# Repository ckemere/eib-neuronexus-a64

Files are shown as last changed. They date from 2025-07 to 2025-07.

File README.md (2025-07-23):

# EIB for Neuronexus A64 probes

- 64 electrodes
- Power ground (GND) and amplifier reference (REF) exposed via 2.54mm header
- Compatible with
  [headstage-64](https://github.com/open-ephys/onix-headstage-64) Rev. 1.3 and 1.3B, [headstage-64s](https://github.com/open-ephys/onix-headstage-64s), and the [low-profile headstage](https://open-ephys.org/acquisition-system/low-profile-spi-headstage-64ch). 

# Notes about this fork:
This repository is a fork of https://github.com/open-ephys/eib-neuronexus-a64. 
I've replaced the through-hole connector from
that design with a SMD connector (i.e., FOLC-110-02-S-Q-P). While this makes
alignment of the two connectors much more challenging, it allows for
fabrication with a standard 2-layer PCB process with 6 mil trace/space.

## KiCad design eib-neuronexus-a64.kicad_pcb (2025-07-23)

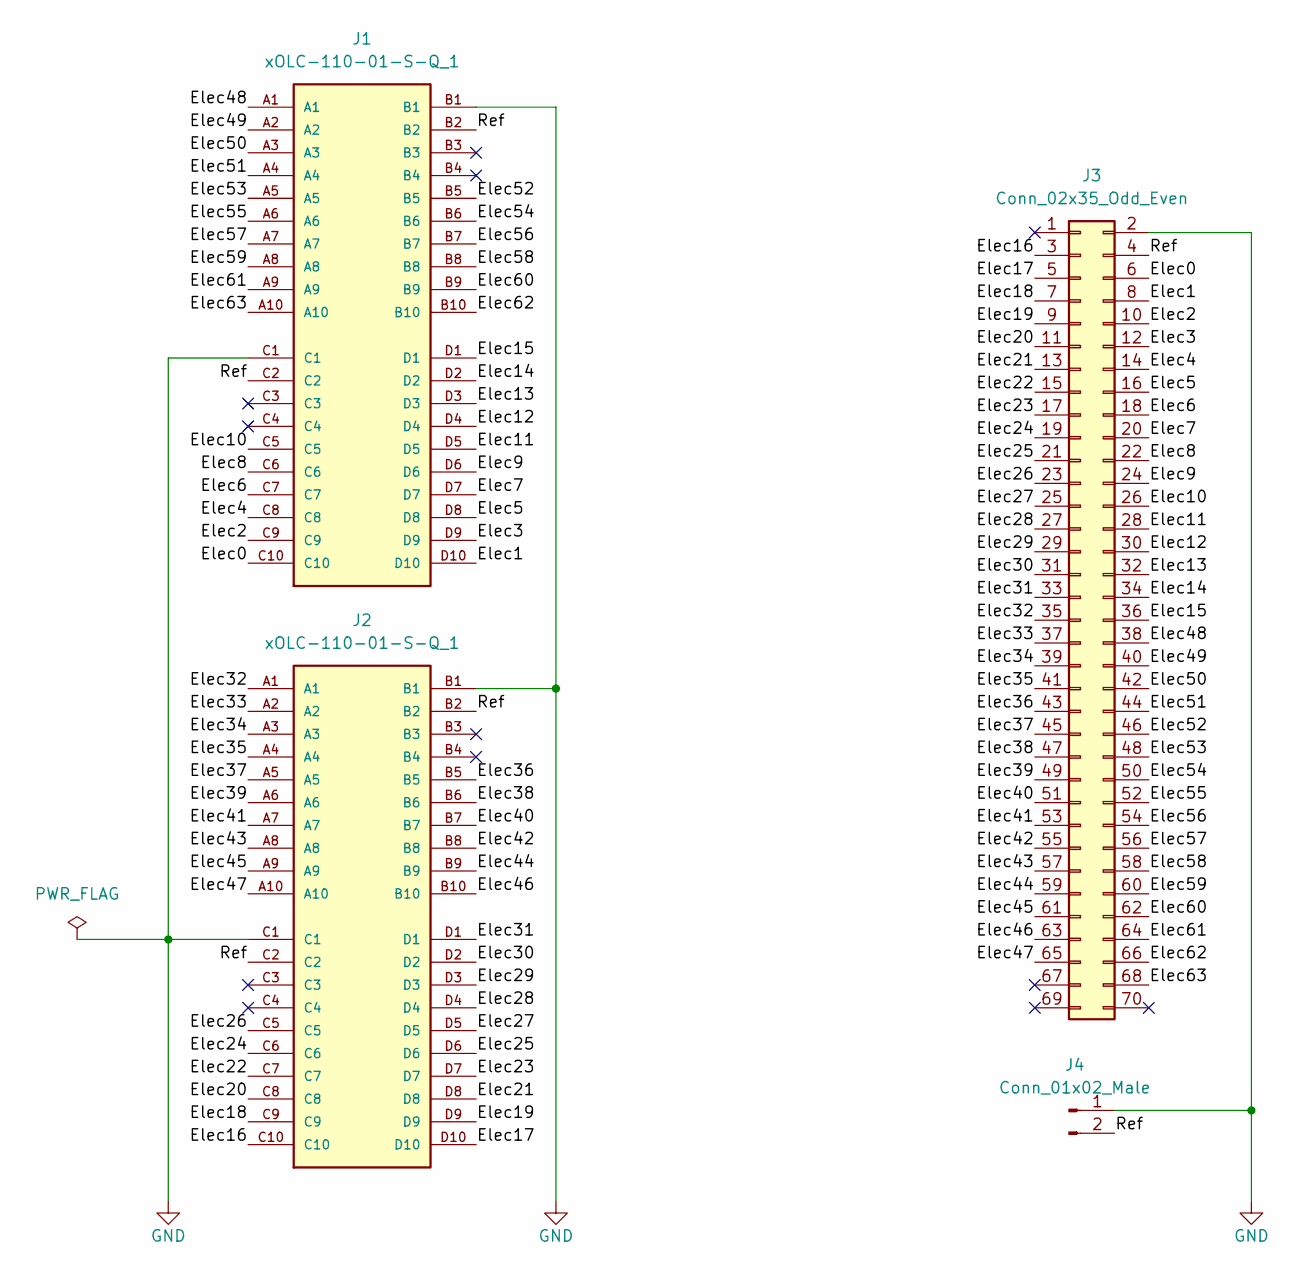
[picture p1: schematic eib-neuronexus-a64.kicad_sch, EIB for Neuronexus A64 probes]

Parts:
J1, J2: xOLC-110-01-S-Q_1; SAMTEC_FOLC-110-02-S-Q-LC
J3: Conn_02x35_Odd_Even; HIROSE_DF40C(2.0)-70DS-0.4V(51)
J4: Conn_01x02_Male; PinHeader_1x02_P2.54mm_Horizontal

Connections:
/Elec0: J1.C10, J3.6
/Elec1: J1.D10, J3.8
/Elec2: J1.C9, J3.10
/Elec3: J1.D9, J3.12
/Elec4: J1.C8, J3.14
/Elec5: J1.D8, J3.16
/Elec6: J1.C7, J3.18
/Elec7: J1.D7, J3.20
/Elec8: J1.C6, J3.22
/Elec9: J1.D6, J3.24
/Elec10: J1.C5, J3.26
/Elec11: J1.D5, J3.28
/Elec12: J1.D4, J3.30
/Elec13: J1.D3, J3.32
/Elec14: J1.D2, J3.34
/Elec15: J1.D1, J3.36
/Elec16: J2.C10, J3.3
/Elec17: J2.D10, J3.5
/Elec18: J2.C9, J3.7
/Elec19: J2.D9, J3.9
/Elec20: J2.C8, J3.11
/Elec21: J2.D8, J3.13
/Elec22: J2.C7, J3.15
/Elec23: J2.D7, J3.17
/Elec24: J2.C6, J3.19
/Elec25: J2.D6, J3.21
/Elec26: J2.C5, J3.23
/Elec27: J2.D5, J3.25
/Elec28: J2.D4, J3.27
/Elec29: J2.D3, J3.29
/Elec30: J2.D2, J3.31
/Elec31: J2.D1, J3.33
/Elec32: J2.A1, J3.35
/Elec33: J2.A2, J3.37
/Elec34: J2.A3, J3.39
/Elec35: J2.A4, J3.41
/Elec36: J2.B5, J3.43
/Elec37: J2.A5, J3.45
/Elec38: J2.B6, J3.47
/Elec39: J2.A6, J3.49
/Elec40: J2.B7, J3.51
/Elec41: J2.A7, J3.53
/Elec42: J2.B8, J3.55
/Elec43: J2.A8, J3.57
/Elec44: J2.B9, J3.59
/Elec45: J2.A9, J3.61
/Elec46: J2.B10, J3.63
/Elec47: J2.A10, J3.65
/Elec48: J1.A1, J3.38
/Elec49: J1.A2, J3.40
/Elec50: J1.A3, J3.42
/Elec51: J1.A4, J3.44
/Elec52: J1.B5, J3.46
/Elec53: J1.A5, J3.48
/Elec54: J1.B6, J3.50
/Elec55: J1.A6, J3.52
/Elec56: J1.B7, J3.54
/Elec57: J1.A7, J3.56
/Elec58: J1.B8, J3.58
/Elec59: J1.A8, J3.60
/Elec60: J1.B9, J3.62
/Elec61: J1.A9, J3.64
/Elec62: J1.B10, J3.66
/Elec63: J1.A10, J3.68
/Ref: J1.B2, J1.C2, J2.B2, J2.C2, J3.4, J4.2
GND: J1.B1, J1.C1, J2.B1, J2.C1, J3.2, J4.1

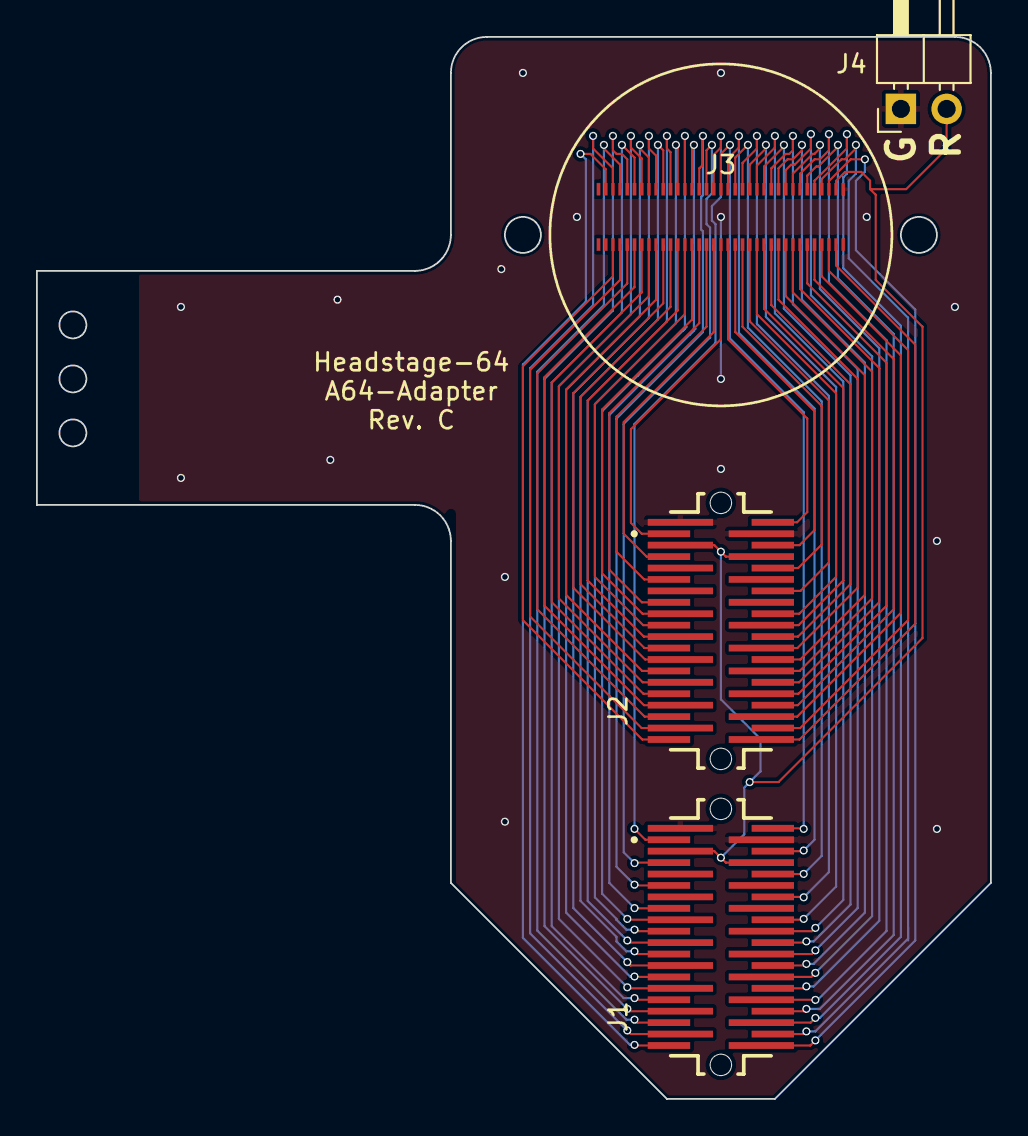
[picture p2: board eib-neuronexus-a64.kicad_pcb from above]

Board: 2 copper layers, 53.0 x 59.0 mm, 4 parts (0 on the bottom side), 66 nets.
